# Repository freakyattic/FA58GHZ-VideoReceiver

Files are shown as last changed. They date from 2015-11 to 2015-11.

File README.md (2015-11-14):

# FA58GHZ-VideoReceiver

This is the repository for the FA58GHZ ( FreakyAttic 5.8GHZ ) RF Video Receiver Module with the following characteristics:

- Video OSD with interactive menus to configure all module functions.
- 40 channels (5 bands), supporting most of the 5.8GHz video transmitters
- Battery monitor with audio warning alarm.
- Fan output for lens defogging with multiple options and timers
- Posibility to add and extra RF video receiver for Diversity operation.
- Three user button to handle all the functions.
- Open software and hardware platform, based on Arduino and Eagle PCB, no need for licences and fees!!

This module it is going to be integrated in a FPV goggles like the Fatshark base SD, but It could be used for many other platforms.

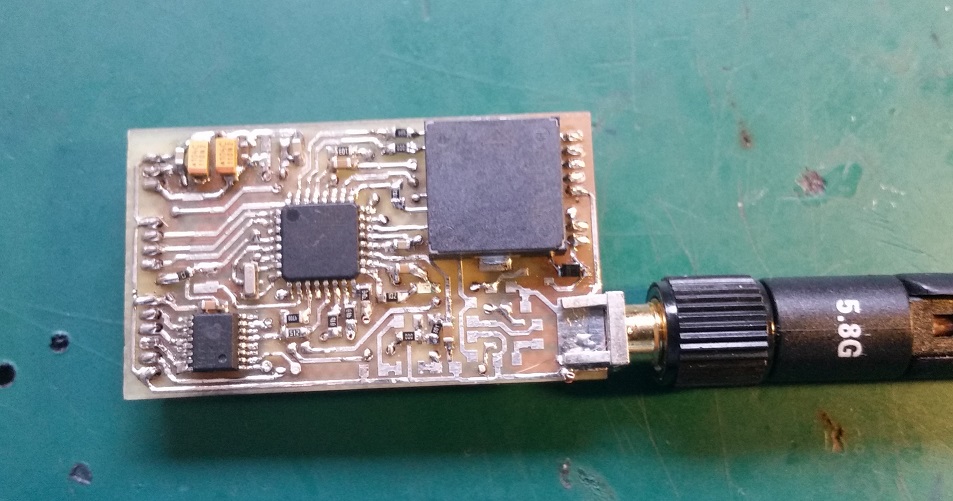
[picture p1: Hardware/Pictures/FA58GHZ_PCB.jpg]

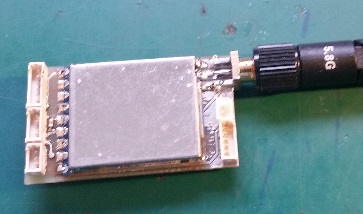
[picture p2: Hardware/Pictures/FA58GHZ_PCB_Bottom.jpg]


# ---PROJECT UNDER DEVELOPMENT ---

# FA58GHZ Schematic
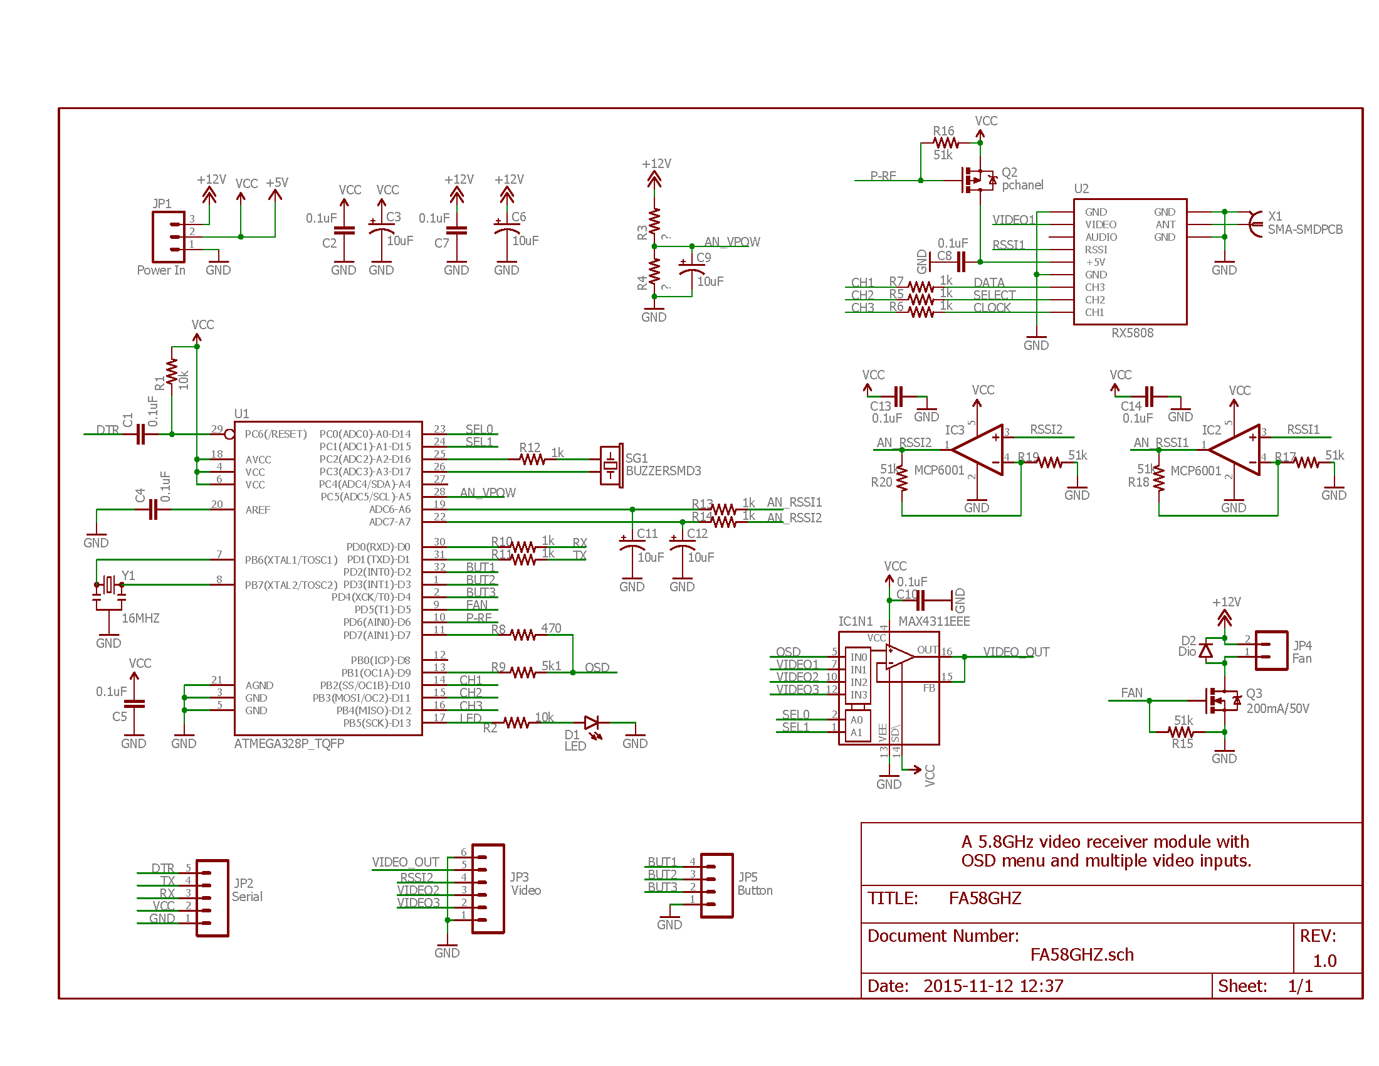
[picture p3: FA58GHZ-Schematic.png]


# Few pictures

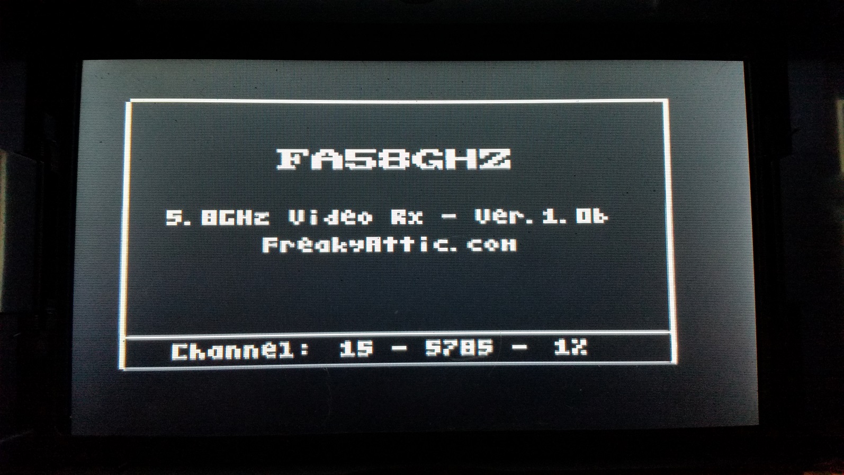
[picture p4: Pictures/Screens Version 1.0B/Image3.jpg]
Intro Screen


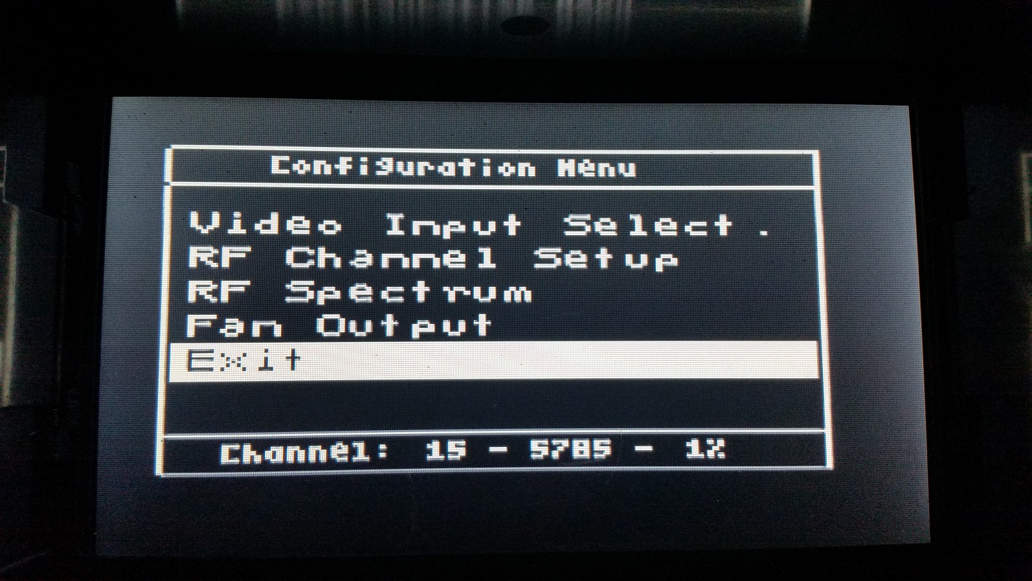
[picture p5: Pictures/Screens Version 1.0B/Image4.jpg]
Main Screen


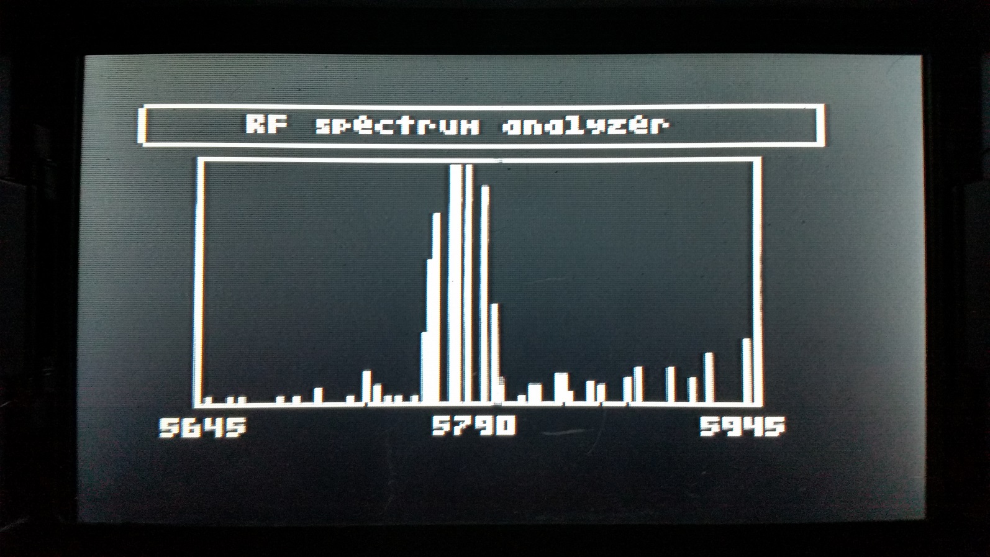
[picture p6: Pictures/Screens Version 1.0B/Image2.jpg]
Spect. Screen


Spect. Screen

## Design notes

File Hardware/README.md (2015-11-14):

# FA58GHZ Hardware

The hardware is developed using Eagle CAD software, using the Freeware license.

# Schematic
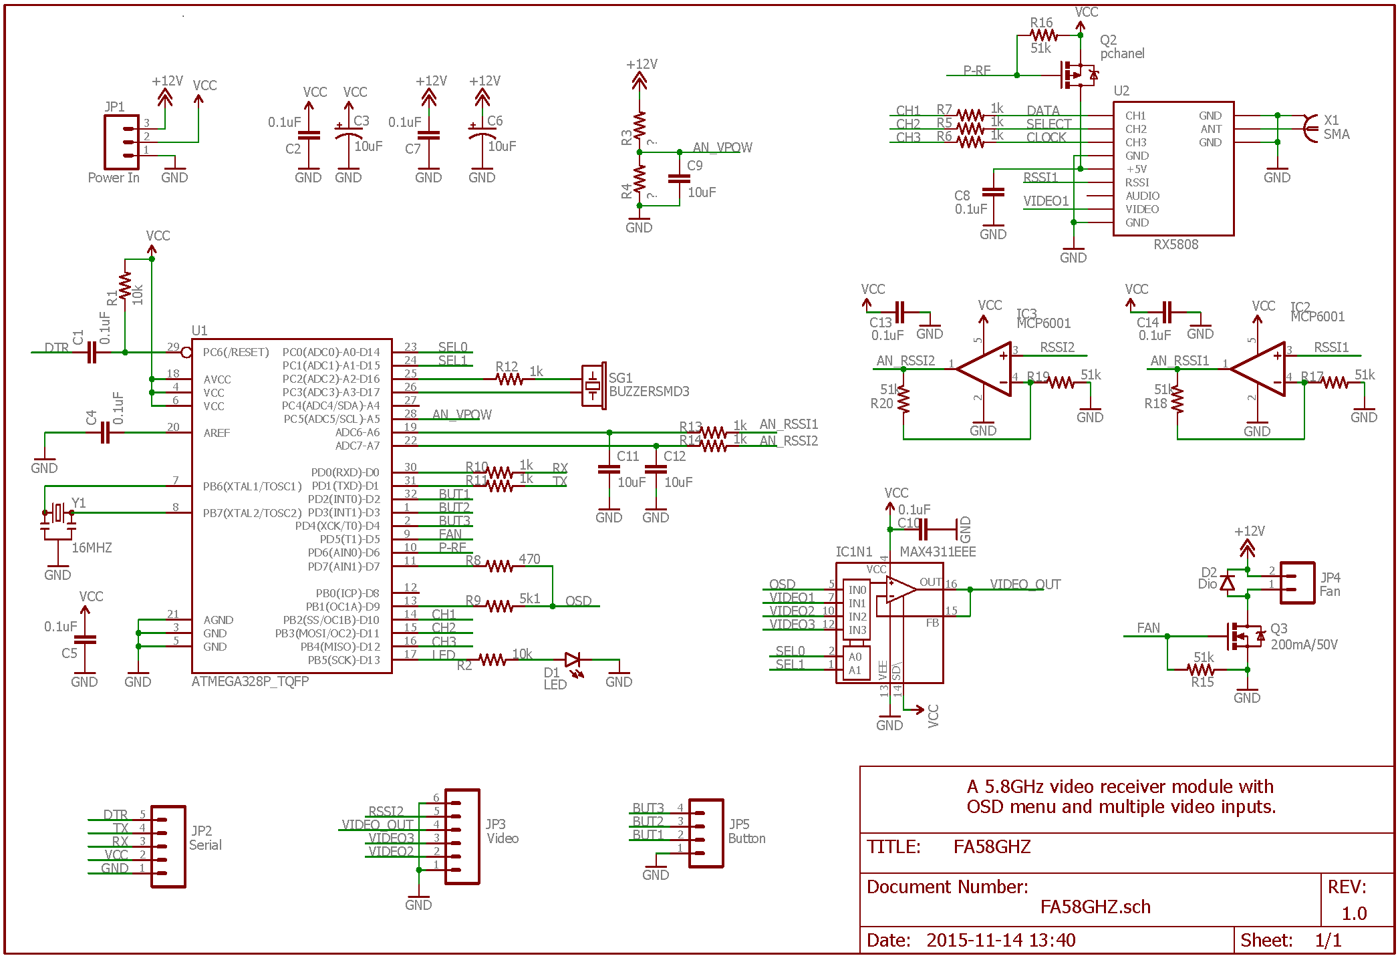
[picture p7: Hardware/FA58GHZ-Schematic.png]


# PCB

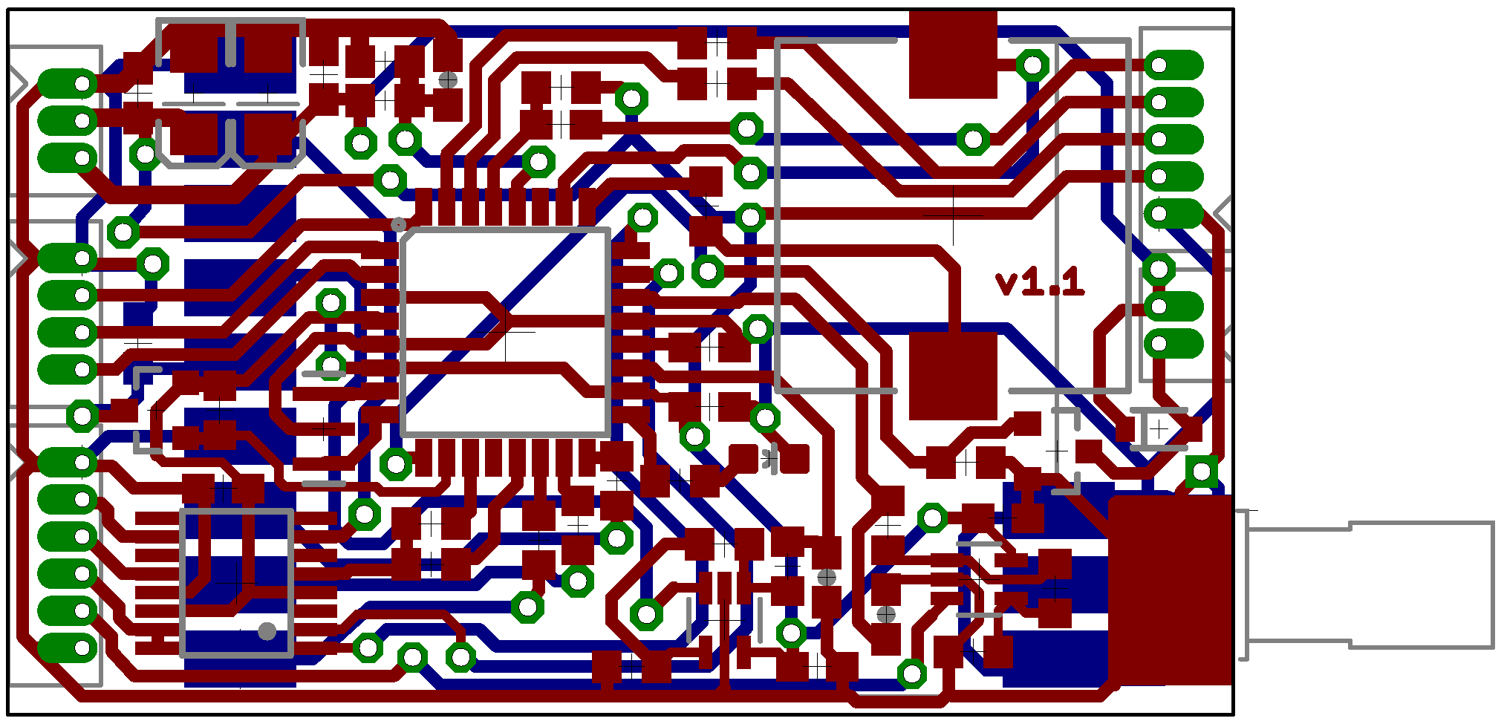
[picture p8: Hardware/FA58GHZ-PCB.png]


# ---PROJECT UNDER DEVELOPMENT---

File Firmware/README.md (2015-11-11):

# FA58GHZ Firmware

The firmware is based in Arduino, you can use Arduino or Atmel Studio with the Arduino pluging.

It uses the Arduino Library TVOut with minor modifications (https://code.google.com/p/arduino-tvout/) which is included in this folder. To install, copy the content of the ZIP file into (Arduino Folder)\libraries. The TVOut library has been modified to add the Pause and Resume functions, therefore It's recommended to use this freakyattic version instead of the original.

Right now the software it is in Beta version, you could use it but not all the functions are fully tested.

Current Firmware Version: 1.01 Beta

### TODO List
- Power control of RF Module, will be implemented with hardware PCB
- Diversity Mode: Add 2 RF receivers and use the RSSI to switch between them.

### DONE List
- Fan menu and options
- Manual Selection of RF Video Channel.
- RF Spectrum analyser.
- Handling the RF module and SPI functions.
- Starting coding ;)

# ---PROJECT UNDER DEVELOPMENT---

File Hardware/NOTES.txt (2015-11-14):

	FA58GHZ Video RF RX
	
-----TODO	-------------------------------------------------

Version 1.1:
	-

----DONE	-------------------------------------------------	

Version 1.0
	-Change fan diode footprint for a bigger one.
	-Wrong footpring for OPamp IC2 IC3
	-Fix problems with RF wrong pinout.

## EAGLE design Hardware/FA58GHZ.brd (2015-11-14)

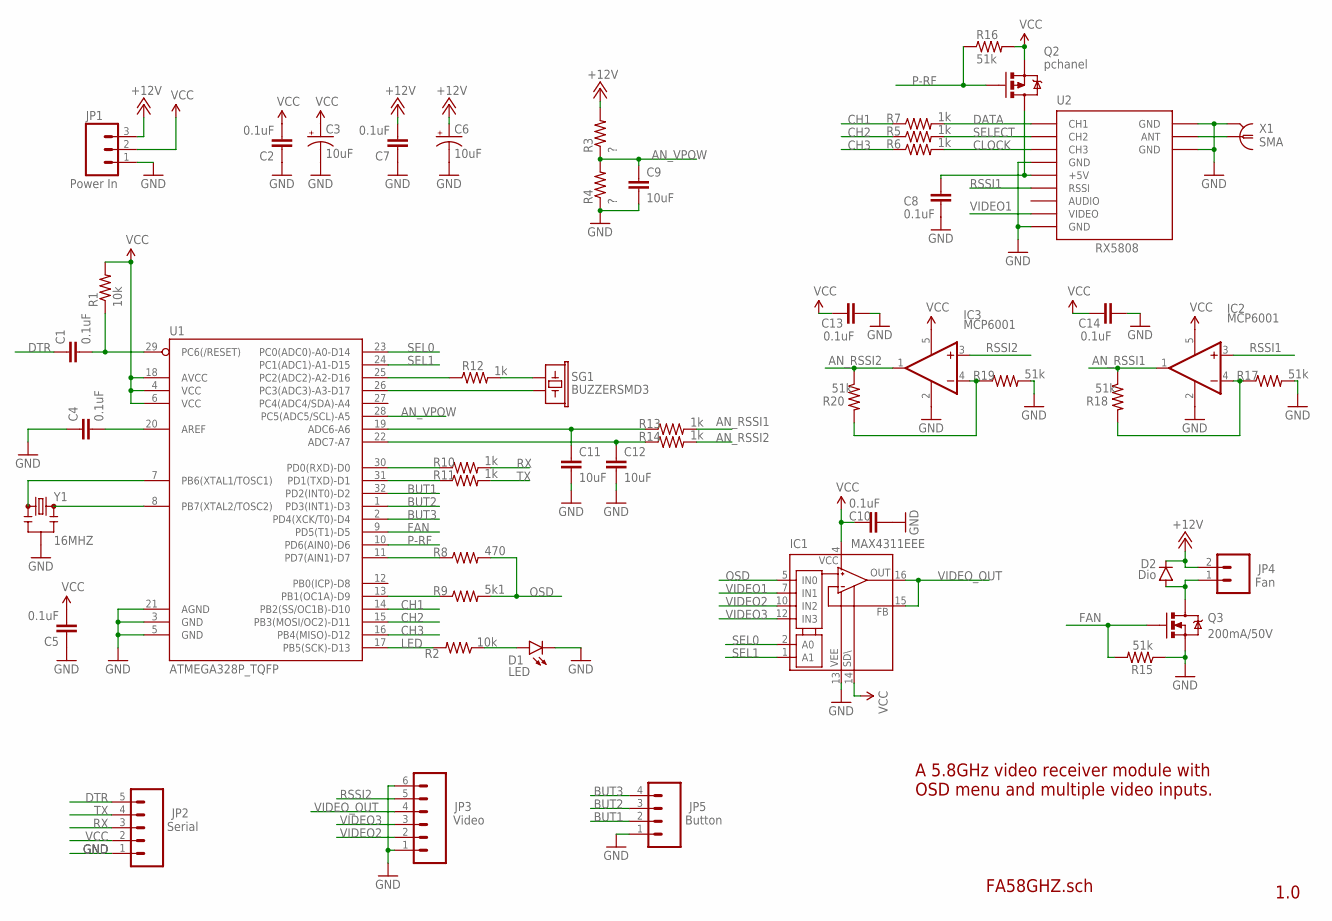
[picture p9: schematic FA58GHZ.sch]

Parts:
C1, C2, C4, C5, C7, C8, C10, C13, C14: 0.1uF; C0603
C3, C6: 10uF; EIA3216
C9, C11, C12: 10uF; 0603-CAP
D1: LED; LED-0603
D2: Dio; SOD-323
IC1: MAX4311EEE; QSOP16
IC2, IC3: MCP6001; SC70-5
JP1: Power In; 1X03-1.27MM-OFFSET
JP2: Serial; 1X05-1.27MM-OFFSET
JP3: Video; 1X06-1.27MM-OFFSET
JP4: Fan; 1X02-1.27MM-OFFSET
JP5: Button; 1X04-1.27MM-OFFSET
Q2: pchanel; SOT23-3
Q3: 200mA/50V; SOT23-3
R1, R2: 10k; R0603
R3, R4: ?; R0603
R5, R6, R7, R10, R11, R12, R13, R14: 1k; R0603
R8: 470; R0603
R9: 5k1; R0603
R15, R16, R17, R18, R19, R20: 51k; R0603
SG1: BUZZERSMD3; BUZZER-12X12X3MM
U1: ATMEGA328P_TQFP; TQFP32-08
U2: RX5808
X1: SMA; SMA-PCB
Y1: 16MHZ; RESONATOR-SMD

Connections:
+12V: C6.A (+), C7.2, D2.C, JP1.3, JP4.2, R3.2
AN_RSSI1: IC2.1 (OUT), R13.2, R18.1
AN_RSSI2: IC3.1 (OUT), R14.2, R20.1
AN_VPOW: C9.1, R3.1, R4.2, U1.28 (PC5(ADC5/SCL)-A5)
BUT1: JP5.2, U1.32 (PD2(INT0)-D2)
BUT2: JP5.3, U1.1 (PD3(INT1)-D3)
BUT3: JP5.4, U1.2 (PD4(XCK/T0)-D4)
CH1: R7.1, U1.14 (PB2(SS/OC1B)-D10)
CH2: R5.1, U1.15 (PB3(MOSI/OC2)-D11)
CH3: R6.1, U1.16 (PB4(MISO)-D12)
CLOCK: R6.2, U2.P$7 (CH3)
DATA: R7.2, U2.P$9 (CH1)
DTR: C1.1, JP2.5
FAN: Q3.1 (G), R15.2, U1.9 (PD5(T1)-D5)
GND: C2.1, C3.C (-), C4.1, C5.1, C6.C (-), C7.1, C8.2, C9.2, C10.1, C11.2, C12.2, C13.2, C14.2, D1.C, IC1.13 (V-), IC2.2 (V-), IC3.2 (V-), JP1.1, JP2.1, JP3.1, JP3.6, JP5.1, Q3.2 (S), R4.1, R15.1, R17.2, R19.2, U1.3 (GND), U1.5 (GND), U1.21 (AGND), U2.P$1 (GND), U2.P$6 (GND), U2.P$10 (GND), U2.P$12 (GND), X1.P$1@1 (2), X1.P$1@2 (2), Y1.2
LED: R2.2, U1.17 (PB5(SCK)-D13)
unnamed: U1.8 (PB7(XTAL2/TOSC2)), Y1.3
unnamed: U1.7 (PB6(XTAL1/TOSC1)), Y1.1
unnamed: C1.2, R1.1, U1.29 (PC6(/RESET))
unnamed: C4.2, U1.20 (AREF)
unnamed: D1.A, R2.1
unnamed: R8.1, U1.11 (PD7(AIN1)-D7)
unnamed: R9.1, U1.13 (PB1(OC1A)-D9)
unnamed: R10.1, U1.30 (PD0(RXD)-D0)
unnamed: R11.1, U1.31 (PD1(TXD)-D1)
unnamed: R12.1, U1.25 (PC2(ADC2)-A2-D16)
unnamed: SG1.2, U1.26 (PC3(ADC3)-A3-D17)
unnamed: R12.2, SG1.1
unnamed: D2.A, JP4.1, Q3.3 (D)
unnamed: IC2.4 (-IN), R17.1, R18.2
unnamed: IC3.4 (-IN), R19.1, R20.2
unnamed: U2.P$11 (ANT), X1.P$2 (1)
unnamed: C12.1, R14.1, U1.22 (ADC7-A7)
unnamed: C11.1, R13.1, U1.19 (ADC6-A6)
unnamed: C8.1, Q2.3 (D), U2.P$5 (+5V)
OSD: IC1.5 (IN0), R8.2, R9.2
P-RF: Q2.1 (G), R16.1, U1.10 (PD6(AIN0)-D6)
RSSI1: IC2.3 (+IN), U2.P$4 (RSSI)
RSSI2: IC3.3 (+IN), JP3.5
RX: JP2.3, R10.2
SEL0: IC1.2 (A0), U1.23 (PC0(ADC0)-A0-D14)
SEL1: IC1.1 (A1), U1.24 (PC1(ADC1)-A1-D15)
SELECT: R5.2, U2.P$8 (CH2)
TX: JP2.4, R11.2
VCC: C2.2, C3.A (+), C5.2, C10.2, C13.1, C14.1, IC1.4 (V+), IC1.14 (!SHDN), IC2.5 (V+), IC3.5 (V+), JP1.2, JP2.2, Q2.2 (S), R1.2, R16.2, U1.4 (VCC), U1.6 (VCC), U1.18 (AVCC)
VIDEO1: IC1.7 (IN1), U2.P$2 (VIDEO)
VIDEO2: IC1.10 (IN2), JP3.2
VIDEO3: IC1.12 (IN3), JP3.3
VIDEO_OUT: IC1.15 (FB), IC1.16 (OUT), JP3.4

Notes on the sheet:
A 5.8GHz video receiver module with OSD menu and multiple video inputs.
1.0
FA58GHZ.sch

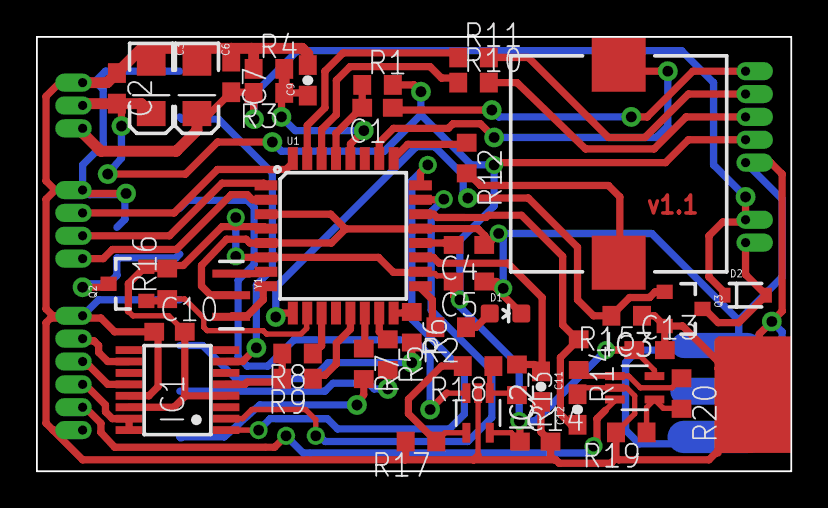
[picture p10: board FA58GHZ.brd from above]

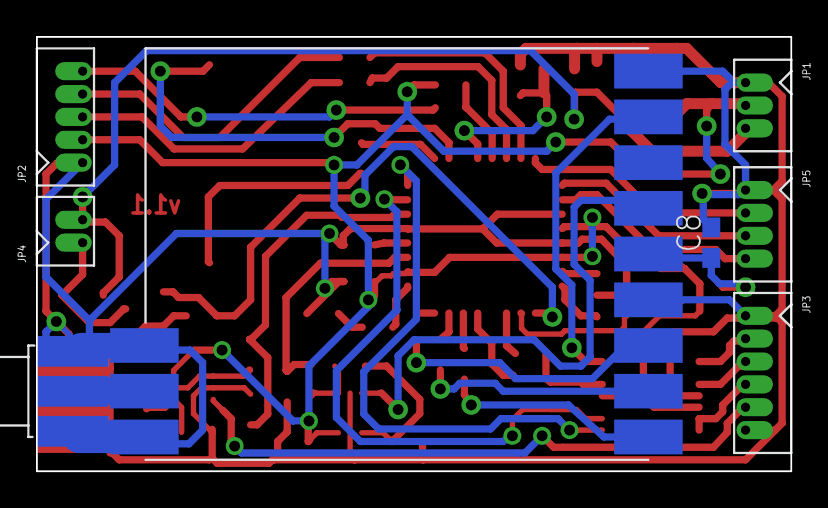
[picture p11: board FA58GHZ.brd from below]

Board: 2 copper layers, 41.9 x 24.1 mm, 51 parts (8 on the bottom side), 49 nets.

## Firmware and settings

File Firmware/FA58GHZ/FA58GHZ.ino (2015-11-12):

/*
	FA58GHZ.ino
 
	Created: 2015-11-08 19:38:50
	Author: FreakyAttic.com
 
 -------------------------------------------------------------------------------------
	 The MIT License (MIT)

	 Copyright (c) 2015 FreakyAttic.com

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
*/ 

#include <avr/pgmspace.h>
#include <EEPROM.h>
#include <stdint.h>
#include <TVout.h>
#include <fontALL.h>

#include "Definitions.h"
#include "RTC6715.h"


/*****************************************************/
/*		GLOBAL VARIABLES							 */
/*****************************************************/
	
	unsigned long	_millisLED;		//LED status
	unsigned long	_millisFAN, _millisFANMode;	

	uint8_t		eep_VideoInput;		// 0: RF1, 1:RF2, 2:EXT-Video, 3:Diversity

	uint8_t		eep_RFchannel;		//EEPROM channel saved.
	uint16_t	eep_RSSIMax;
	uint16_t	eep_RSSIMin;
	
	uint8_t		eep_FANTimeInc;		//FAN Increment
	uint8_t		eep_FANPower;		//FAN Power
	uint8_t		eep_FANMode;		//FAN Mode
	
	uint8_t		eep_BattEnable;		//Battery Monitor
	uint8_t		eep_BattType;
	uint16_t	eep_BattCell;
	uint16_t	epp_BattCalib;
	
	stateButton		_buttonMode = sbutton_idle;
	stateButton		_buttonNext = sbutton_idle;
	stateButton		_buttonFan  = sbutton_idle;
	
/*****************************************************/
/*		FUNCTIONS									 */
/*****************************************************/
void setup ( void )
{	
//Pin out Initialization
	
	//RF Module
		pinMode (slaveSelectPin, OUTPUT);
		pinMode (spiDataPin, OUTPUT);
		pinMode (spiClockPin, OUTPUT);
		
		pinMode (PowerRF, OUTPUT);
			digitalWrite(PowerRF, HIGH);	//Power OFf
			
	//Video Multiplexer
		pinMode (VideoSel0, OUTPUT);
		pinMode (VideoSel1, OUTPUT);
			digitalWrite(VideoSel0, LOW);	//IN0 selected
			digitalWrite(VideoSel1, LOW);
	
	//Buttons
		pinMode(pinbuttonMode, INPUT);
			digitalWrite(pinbuttonMode, INPUT_PULLUP);
		pinMode(pinbuttonNext, INPUT);
			digitalWrite(pinbuttonNext, INPUT_PULLUP);
		pinMode(pinbuttonFan, INPUT);
			digitalWrite(pinbuttonFan, INPUT_PULLUP);			
	
	// Buzzer
		pinMode(buzzer, OUTPUT);
		pinMode(buzzern, OUTPUT);
		digitalWrite(buzzer, LOW);
		digitalWrite(buzzern, LOW);
	
	//LED	
		pinMode(led, OUTPUT);
			digitalWrite(led, HIGH);

	
	//External Fan
		pinMode(pinFan, OUTPUT); 
			digitalWrite(pinFan, HIGH);

	//Ini Beeping
		for(char i = 0; i<6; i++)
		{
			digitalWrite(led, HIGH);
			beep(10);
			digitalWrite(led, LOW);
			delay(100);
		}
		
	//EEPROM Initialization	
		Load_EEPROM();

	//RF Module ini
		RF_Ini(eep_RFchannel);

	// OSD Initialization
		OSD_Ini();
		
	//Finish Initialization
		_debug(F("Board initialized ..."));
		
	_millisLED = millis();	//LED status
	_millisFAN = millis();				
}

void loop()
{
	
//Button Tasks
	Buttons_Tasks();
	
//OSD Tasks
	OSD_Tasks();

//FAN Tasks
	FAN_Tasks();	
	
//LED Status
	if(millis() > _millisLED)
	{
		_millisLED = millis() + 500;
		if(digitalRead(led))
		digitalWrite(led, LOW);
		else
		digitalWrite(led, HIGH);
		
	}
}


/*****************************************************/
/*		FUNCTIONS									 */
/*****************************************************/

void beep(uint16_t time)
{
	unsigned long  targetms;
	
	targetms = millis() + time;
	while( millis() < targetms )
	{
		//Toggle the pins
		digitalWrite(buzzer, HIGH);
		digitalWrite(buzzern, LOW);
		delayMicroseconds(100);
		digitalWrite(buzzer, LOW);
		digitalWrite(buzzern, HIGH);
		delayMicroseconds(100);
	}
	
	digitalWrite(buzzer, LOW); //Disable Buzzer
	digitalWrite(buzzern, LOW);
}

void	_debug	( const __FlashStringHelper *description )
{
#ifdef DEBUG
	static char ini = 0;
	if(!ini)
	{
		Serial.begin(115200);
		Serial.print(F("\n\n\n\rFA58GHZ RF Video Module - Ver. "));
		Serial.println(FIRMWAREVER);
		Serial.print(F("   By Freakyattic.com - "));
		Serial.println(F(__DATE__));
		Serial.println(F(" "));
		
		ini++;
	}
	Serial.println(description);
#endif
}

void	Load_EEPROM		( void )
{
	uint16_t	_address;
	uint8_t		_value0, _value1;
	
	//IF EEPROM structure changed, modify EEPROM_VER in Definitions.h
	
	_address = 0;
	_value0 = EEPROM.read(_address++);
	
	//Check if different version, then Factory Default.
	if( (_value0 != EEPROM_VER) || ( !digitalRead(pinbuttonMode)&!digitalRead(pinbuttonFan)))
	{
		_debug(F("EEPROM: Loading default values"));
		_address = 0;
		EEPROM.write(_address++, EEPROM_VER);
		
		//Default values
		eep_VideoInput	= 0;
		eep_RFchannel	= 0x15;		//RF
		eep_RSSIMax		= 340;
		eep_RSSIMin		= 145;
		eep_FANTimeInc	= 3;		//FAN
		eep_FANPower	= 0;
		eep_FANMode		= 0;
		eep_BattEnable	= 0;		//Battery
		eep_BattType	= 2;
		eep_BattCell	= 3000;
		epp_BattCalib	= 3167;
		
		Save_EEPROM();
	}
	
	//Load Data
	eep_VideoInput	= EEPROM.read(_address++);
	eep_RFchannel	= EEPROM.read(_address++);
	eep_RSSIMax		= ((EEPROM.read(_address++)<<8) | (EEPROM.read(_address++)));
	eep_RSSIMin		= ((EEPROM.read(_address++)<<8) | (EEPROM.read(_address++)));
	eep_FANTimeInc	= EEPROM.read(_address++);
	eep_FANPower	= EEPROM.read(_address++);
	eep_FANMode		= EEPROM.read(_address++);
	eep_BattEnable	= EEPROM.read(_address++);
	eep_BattType	= EEPROM.read(_address++);
	eep_BattCell	= ((EEPROM.read(_address++)<<8) | (EEPROM.read(_address++)));
	epp_BattCalib	= ((EEPROM.read(_address++)<<8) | (EEPROM.read(_address++)));

	_debug(F("EEPROM: Configuration loaded"));
}

void	Save_EEPROM		( void )
{
	uint8_t		_address = 1;
	
//Save Data
	EEPROM.write(_address++,eep_VideoInput);
	EEPROM.write(_address++,eep_RFchannel);				//RF
	EEPROM.write(_address++,highByte(eep_RSSIMax));	
	EEPROM.write(_address++,lowByte(eep_RSSIMax));
	EEPROM.write(_address++,highByte(eep_RSSIMin));
	EEPROM.write(_address++,lowByte(eep_RSSIMin));
	EEPROM.write(_address++,eep_FANTimeInc);			//FAN
	EEPROM.write(_address++,eep_FANPower);
	EEPROM.write(_address++,eep_FANMode);
	EEPROM.write(_address++,eep_BattEnable);			//Battery
	EEPROM.write(_address++,eep_BattType);
	EEPROM.write(_address++,highByte(eep_BattCell));
	EEPROM.write(_address++,lowByte(eep_BattCell));
	EEPROM.write(_address++,highByte(epp_BattCalib));
	EEPROM.write(_address++,lowByte(epp_BattCalib));

	_debug(F("EEPROM: Configuration saved"));
}

void	VideoSelect		( uint8_t _input)
{
	switch(_input)
	{
		case 1:			//RF Module 1
			RF_ChannelSet(eep_RFchannel);	//Set saved channel
			OSDScreen_Off();
			digitalWrite(VideoSel0, HIGH);
			digitalWrite(VideoSel1, LOW);
			break;
		case 2:			//RF Module 2
			RF_ChannelSet(eep_RFchannel);	//Set saved channel
			OSDScreen_Off();
			digitalWrite(VideoSel0, LOW);
			digitalWrite(VideoSel1, HIGH);
			break;
		case 3:			//Ext Video
			OSDScreen_Off();
			digitalWrite(VideoSel0, HIGH);
			digitalWrite(VideoSel1, HIGH);
			break;
		default:
		case 0:			//OSD
			OSDScreen_Main();
			digitalWrite(VideoSel0, LOW);
			digitalWrite(VideoSel1, LOW);
			break;
	}
}

/*****************************************************/
/*		Buttons  									 */
/*****************************************************/

void	Buttons_Tasks		( void )
{
	static unsigned long	_millisButtMode = 0;
	static unsigned long	_millisButtNext = 0;
	static unsigned long	_millisButtFan  = 0;
	
//Button Mode
	if(!digitalRead(pinbuttonMode))	
	{
		if(_millisButtMode == 0)
		{
			_millisButtMode = millis();
		}
	}
	else
	{
		if(_millisButtMode != 0)
		{
			_millisButtMode = millis() - _millisButtMode;
			
			if(_millisButtMode > BUTTON_GLITCHES)
			{
				if(_millisButtMode < BUTTON_CLICK)
				{
					_buttonMode = sbutton_click;
				}
				else if(_millisButtMode < BUTTON_HOLD)
				{
					_buttonMode = sbutton_hold;
				}
				else if(_millisButtMode < BUTTON_HOLDLONG)
				{
					_buttonMode = sbutton_holdlong;
				}
			}
			_millisButtMode = 0;
		}
	}
	
//Button Next
	if(!digitalRead(pinbuttonNext))
	{
		if(_millisButtNext == 0)
		{
			_millisButtNext = millis();
		}
	}
	else
	{
		if(_millisButtNext != 0)
		{
			_millisButtNext = millis() - _millisButtNext;
		
			if(_millisButtNext > BUTTON_GLITCHES)
			{
				if(_millisButtNext < BUTTON_CLICK)
				{
					_buttonNext = sbutton_click;
				}
				else if(_millisButtNext < BUTTON_HOLD)
				{
					_buttonNext = sbutton_hold;
				}
				else if(_millisButtNext < BUTTON_HOLDLONG)
				{
					_buttonNext = sbutton_holdlong;
				}
			}
			_millisButtNext = 0;
		}
	}	

//Button FAN
	if(!digitalRead(pinbuttonFan))
	{
		if(_millisButtFan == 0)
		{
			_millisButtFan = millis();
		}
	}
	else
	{
		if(_millisButtFan != 0)
		{
			_millisButtFan = millis() - _millisButtFan;
			
			if(_millisButtFan > BUTTON_GLITCHES)
			{
				if(_millisButtFan < BUTTON_CLICK)
				{
					_buttonFan = sbutton_click;
				}
				else if(_millisButtFan < BUTTON_HOLD)
				{
					_buttonFan = sbutton_hold;
				}
				else if(_millisButtFan < BUTTON_HOLDLONG)
				{
					_buttonFan = sbutton_holdlong;
				}
			}
			_millisButtFan = 0;
		}
	}
}

// BUT ------------------------------------------------------

	void	Clear_ButtonStates	( void )
	{
		_buttonMode = sbutton_idle;
		_buttonNext = sbutton_idle;
		_buttonFan = sbutton_idle;
	}

// MODE BUT ------------------------------------------------------
	uint8_t	isbuttonMode_Click ( void )
	{
		if(_buttonMode== sbutton_click)
		{
			Clear_ButtonStates();	// Only one button allowed at a time
			beep(15);
			return 1;
		}
		return 0;
	}

	uint8_t	isbuttonMode_Hold ( void )
	{
		if(_buttonMode== sbutton_hold)
		{
			Clear_ButtonStates();	// Only one button allowed at a time
			beep(15);
			return 1;
		}
		return 0;
	}

	uint8_t	isbuttonMode_HoldLong ( void )
	{
		if(_buttonMode== sbutton_holdlong)
		{
			Clear_ButtonStates();	// Only one button allowed at a time
			beep(15);
			return 1;
		}
		return 0;
	}

// NEXT BUT ------------------------------------------------------
	uint8_t	isbuttonNext_Click ( void )
	{
		if(_buttonNext == sbutton_click)
		{
			Clear_ButtonStates();	// Only one button allowed at a time
			beep(15);
			return 1;
		}
		return 0;
	}

	uint8_t	isbuttonNext_Hold ( void )
	{
		if(_buttonNext== sbutton_hold)
		{
			Clear_ButtonStates();	// Only one button allowed at a time
			beep(15);
			return 1;
		}
		return 0;
	}

	uint8_t	isbuttonNext_HoldLong ( void )
	{
		if(_buttonNext== sbutton_holdlong)
		{
			Clear_ButtonStates();	// Only one button allowed at a time
			beep(15);
			return 1;
		}
		return 0;
	}

// FAN BUT ------------------------------------------------------
	uint8_t	isbuttonFan_Click ( void )
	{
		if(_buttonFan == sbutton_click)
		{
			Clear_ButtonStates();	// Only one button allowed at a time
			beep(15);
			return 1;
		}
		return 0;
	}

	uint8_t	isbuttonFan_Hold ( void )
	{
		if(_buttonFan== sbutton_hold)
		{
			Clear_ButtonStates();	// Only one button allowed at a time
			beep(15);
			return 1;
		}
		return 0;
	}

	uint8_t	isbuttonFan_HoldLong ( void )
	{
		if(_buttonFan== sbutton_holdlong)
		{
			Clear_ButtonStates();	// Only one button allowed at a time
			beep(15);
			return 1;
		}
		return 0;
	}

	uint8_t	isbutton_AnyPressed( void )
	{
		if( (_buttonFan != sbutton_idle) | (_buttonMode != sbutton_idle) | (_buttonNext != sbutton_idle))
		{
			Clear_ButtonStates();	// Only one button allowed at a time
			beep(15);
			return 1;
		}
		return 0;
	}


/****************************************************/
/*		FAN Tasks									*/
/****************************************************/

void	FAN_Tasks		( void )
{
	static uint8_t  currentPower = FANPOWER_0+1;
	static uint8_t  selectedPower = FANPOWER_0;
	
	if( millis() > _millisFAN)
	{
		if( currentPower != FANPOWER_0)
		{
			currentPower = FANPOWER_0;
			analogWrite(pinFan, currentPower); //off
		}
	}
	else
	{
		if( eep_FANMode == 0)	//Cont.
		{
			if( currentPower != selectedPower)
			{
				currentPower = selectedPower;
				analogWrite(pinFan, currentPower); //Full On	
			}
		}
		else
		{
			if( millis() > _millisFANMode)		//Fan mode
			{
				if( currentPower != selectedPower)
					currentPower = selectedPower;
				else
					currentPower = FANPOWER_0;
					
				analogWrite(pinFan, currentPower);
				
				//Add time
				_millisFANMode = millis();
				switch(eep_FANMode)
				{
					case 1:	_millisFANMode +=  5000; break;
					case 2:	_millisFANMode += 10000; break;
					case 3:	_millisFANMode += 20000; break;
					case 4:	_millisFANMode += 30000; break;
				}
			}
		}
	}

//Click	- Add time
	if(isbuttonFan_Click())
	{
		
	//Increment Timer value		
		if( millis() > _millisFAN) 
			_millisFAN = millis();
		switch(eep_FANTimeInc)
		{
			case 0:	_millisFAN +=  60000; break;
			case 1:	_millisFAN += 120000; break;
			case 2:	_millisFAN += 300000; break;
			case 3:	_millisFAN += 480000; break;
			case 4:	_millisFAN += 600000; break;
		}
		
	//Obtain the selected power
		switch(eep_FANPower)
		{
			case 0:	selectedPower = FANPOWER_100; break; //100%
			case 1:	selectedPower = FANPOWER_80 ; break; //80%
			case 2:	selectedPower = FANPOWER_60 ; break; //60%
			case 3:	selectedPower = FANPOWER_40 ; break; //40%
			case 4:	selectedPower = FANPOWER_20 ; break; //20%
		}
	}
	
//Hold - Stop
	if(isbuttonFan_Hold())
	{
		_millisFAN = millis();
		_millisFANMode = millis();
	}
}

/****************************************************/
/*		Battery Voltage (mV)						*/
/****************************************************/
	uint16_t	BatteryVolt		( void ) 
	{
		static uint8_t test=0;
		unsigned long	_tot = 0;
		
		for( int _x=0; _x < BATT_AVERAGE; _x++)
		{
			_tot += (unsigned long)analogRead(Vin);
		}
		
		_tot /= BATT_AVERAGE;
		//return (uint16_t)_tot;
		return 10120+(test++);
	}
	
	

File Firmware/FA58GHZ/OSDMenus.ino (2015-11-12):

/*
 * OSDMenus.ino
 *
 * Created: 2015-11-09 19:25:08
 *  Author: FreakyAttic.com
 
  -------------------------------------------------------------------------------------
  The MIT License (MIT)

  Copyright (c) 2015 FreakyAttic.com

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
 */ 

	#include "OSDMenus.h"
	
/*********************************************************************************************************/
/*							VARIABLES																	 */
/*********************************************************************************************************/

	TVout			TV;
	OSDSTATES		OSD_State;		//Start with main OSD
	
	uint8_t			_selMenu, _selMenuPrev, _selMenuMax, _selWidth;	//selected menu
	
	unsigned long	_millisMenu, _millisRSSI, _millisSearch;
	uint16_t		_spectrumRSSI_Max, _spectrumRSSI_Min;

/*********************************************************************************************************/
/*							PROTOTYPES																	 */
/*********************************************************************************************************/

	void	SelectedMenu_Ini	( uint8_t _selected, uint8_t _maxItems);
	void	SelectedMenu_Ini	( uint8_t _selected, uint8_t _maxItems,  uint8_t _width);
	void	SelectedMenu_Next	();
	uint8_t	SelectedMenu_Get	();
	
/*********************************************************************************************************/
/*							FUNCTIONS																	 */
/*********************************************************************************************************/

	void	OSD_Ini		( void )
	{
		char _value = 0;
		
		_value = TV.begin(PAL);
		if (_value > 0) {	//ERROR with TV
			while (true) {
				digitalWrite(led, HIGH);
				delay(300);
				digitalWrite(led, LOW);
				delay(300);
			}
		}

		TV.clear_screen();
		
		OSD_State = OSDs_Intro;		//Start with the Intro screen.
		
		_debug(F("OSD: OSD initialized"));
	}

	void	OSD_Tasks	( void )
	{
		uint8_t				_val0;
		uint16_t			_val16_0, _val16_1;
		static uint8_t		_prevIndex;
		static uint8_t		_Update;
		static uint8_t		_autoInc;
		static uint8_t		_fanInc, _fanPower, _fanMode;
		static uint8_t		_batEnable, _batType;
		static uint16_t		_batCell, _batCalib;
		
		switch(OSD_State)
		{
//Off ------------------------------------------------------
			case OSDs_Off:
				_debug(F("OSD: OSD off"));
				Clear_ButtonStates();
				VideoSelect(eep_VideoInput+1); //Select the Video input and switch off OSD
				TV.pause();	//switch off OSD
				OSD_State = OSDs_OffUpdate;
				break;
			case OSDs_OffUpdate:
			
				//Enter Setup
				if( isbuttonMode_Hold() | isbuttonMode_HoldLong() | isbuttonNext_Hold())
					OSD_State = OSDs_Main;
				
				////Select next channel
				//if( isbuttonNext_Click())
				
				//// Automatic Scann
				//if( isbuttonNext_Hold())
					
				break;
				
//Intro - Welcome screen------------------------------------------------------
			case OSDs_Intro:
			
				Clear_ButtonStates();
				VideoSelect(0);		//Select OSD
				TV.clear_screen();
				TV.draw_rect(0,0,TV_WIDTH-1,TV_HEIGHT-1,2);
				
				//Information
				TV.select_font(font8x8ext);
				TV.printPGM(35, 18,PSTR("FA58GHZ"));
				TV.select_font(font4x6);
				TV.printPGM(10, 40,PSTR("5.8GHz Video Rx - Ver."));
				TV.print(FIRMWAREVER);
				TV.printPGM(32, 50,PSTR("FreakyAttic.com"));
				
				//Place information about the channel selected.
				TV.draw_line(0,84, TV_WIDTH-1, 84, 1);
				TV.set_cursor(10, 87);
				TV.print(RF_ChannelGet(),HEX);
				TV.printPGM(PSTR(" - "));
				TV.print(RF_FrequencyGet());
				TV.printPGM(PSTR(" -"));
				
				_millisRSSI = millis();
				_millisMenu = millis()+MENU_TIMEOUT;
				OSD_State = OSDs_IntroUpdate;
				break;
			case OSDs_IntroUpdate:
			
				if((millis() > _millisMenu)|isbutton_AnyPressed())
					OSD_State = OSDs_Main;
				
				//Update RSSI
				if(millis() > _millisRSSI)
				{
					_millisRSSI = millis() + 250;
					
					//RSSI
					TV.set_cursor(60, 87);
					TV.printPGM(PSTR("    "));	//Clean
					TV.set_cursor(60, 87);
					TV.print(RF_RSSIGet(), DEC);
					TV.printPGM(PSTR("%"));
					
					//Voltage
					TV.set_cursor(95, 87);
					TV.print("     ");
					TV.set_cursor(95, 87);
					_val16_1 = BatteryVolt();
					_val16_0 = _val16_1/1000;
					TV.print(_val16_0);
					TV.print(".");
					_val16_0 = (_val16_1 - _val16_0*1000)/10;
					if(_val16_0<10)	TV.print("0");
					TV.print(_val16_0);
					TV.print("v");
				}
				break;				
				
//Main Screen	------------------------------------------------------
			case OSDs_Main:
			
				RF_ChannelSet(eep_RFchannel);	//Select the saved channel
				
				Clear_ButtonStates();
				VideoSelect(0);		//Select OSD			
					
				TV.resume();
				TV.clear_screen();
				
				TV.draw_rect(0,0,TV_WIDTH-1,TV_HEIGHT-1,2);
				TV.select_font(font4x6);
				TV.printPGM(20,3,PSTR("Configuration Menu"));
				TV.draw_line(0,11,TV_WIDTH-1,11,2);
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

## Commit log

2015-11-06 First Backup
    [FA58GHZ.brd, FA58GHZ.sch]
2015-11-07 Backup: Working in the Schematic, Footprints and PCB
    [FA58GHZ.brd, FA58GHZ.sch]
2015-11-08 Finish with the board Schematic, starting to code functions.
    [FA58GHZ.brd, FA58GHZ.sch]
2015-11-10 Firmware Backup: Implementing menus funcitons, problems with the RF module, backup to make tests.
    [Definitions.h, FA58GHZ.ino, OSDMenus.ino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]
2015-11-10 Firmware Backup: Current video files work, but there is a compiler bug, if headers are changed the video library doesnt work.
    [Definitions.h, FA58GHZ.ino, OSDMenus.ino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]
2015-11-10 FIRMWARE Backup: - RF Functions working, need to make PCB for final test. - Need to implement FAN functions.
2015-11-11 FIRMWARE VERSION: 1.01 Beta -Fan menus and hardware functions implemented.
2015-11-12 Backup: Implemented OSD menu for Battery Monitor, needs to test it. - Modifications for the schematic - working on the PCB
    [FA58GHZ.brd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]
2015-11-13 Backup: PCB routing finished, need to run DRC
    [FA58GHZ.brd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]
2015-11-13 -Routing finished and DRC passed with approved warnings
    [FA58GHZ.brd]
2015-11-13 HARDWARE VERSION 1.0: CNC PCB prototype for testing.
    [FA58GHZ.brd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]
2015-11-14 BOARD VER: 1.1 - Fix footprints and pinout problems with RF
    [FA58GHZ.brd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]
2015-11-14 Adding schematic Pictures/FA58GHZ_PCB.jpg

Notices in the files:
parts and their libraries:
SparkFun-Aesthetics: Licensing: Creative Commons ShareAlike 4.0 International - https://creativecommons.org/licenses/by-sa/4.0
